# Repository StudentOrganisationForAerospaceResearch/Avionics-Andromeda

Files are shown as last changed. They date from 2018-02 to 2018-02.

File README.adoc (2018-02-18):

= Andromeda Sensor Development Board

Andromeda is the development board for SOAR's 2018 competition avionics system.

Hardware Designs are incremented by version.
For example; *AndromedaV1* is version 1.

The design files for each version are available along with pdf schematics,
assembly drawings and gerber files.

Each hardware version contains the following design files
----

* ___VX.pro - Kicad project
* ___VX.sch - Kicad main schematic
* ___VX.kicad_pcb - Kicad PCB design
* ___.sch - several hierarchical schematic
* ___V.net - Kicad netlist file
* ___VX-cache.dcm - Kicad component description cache
* ___VX-cache.lib - Kicad component library cache
* ___VX-Schematic.pdf - PDF Schematic
* ___VX-AssemblyDrawing.pdf PDF export of fabrication layer
* Gerbers - Gerber files exported with protel extensions
----

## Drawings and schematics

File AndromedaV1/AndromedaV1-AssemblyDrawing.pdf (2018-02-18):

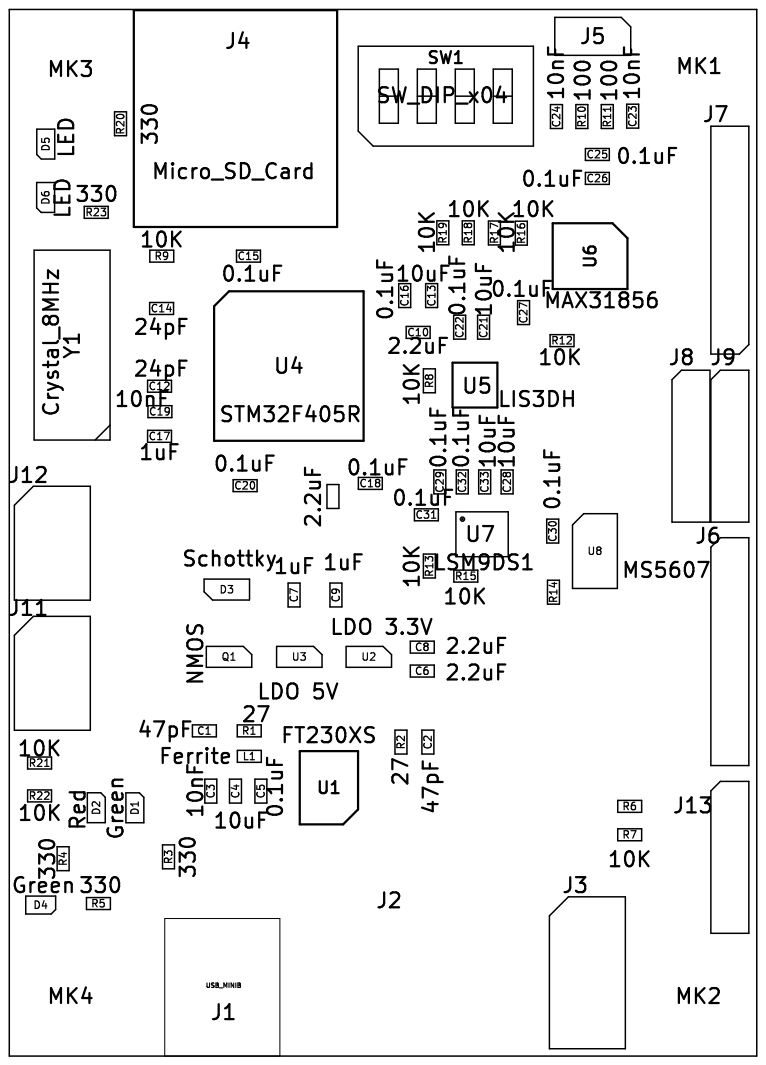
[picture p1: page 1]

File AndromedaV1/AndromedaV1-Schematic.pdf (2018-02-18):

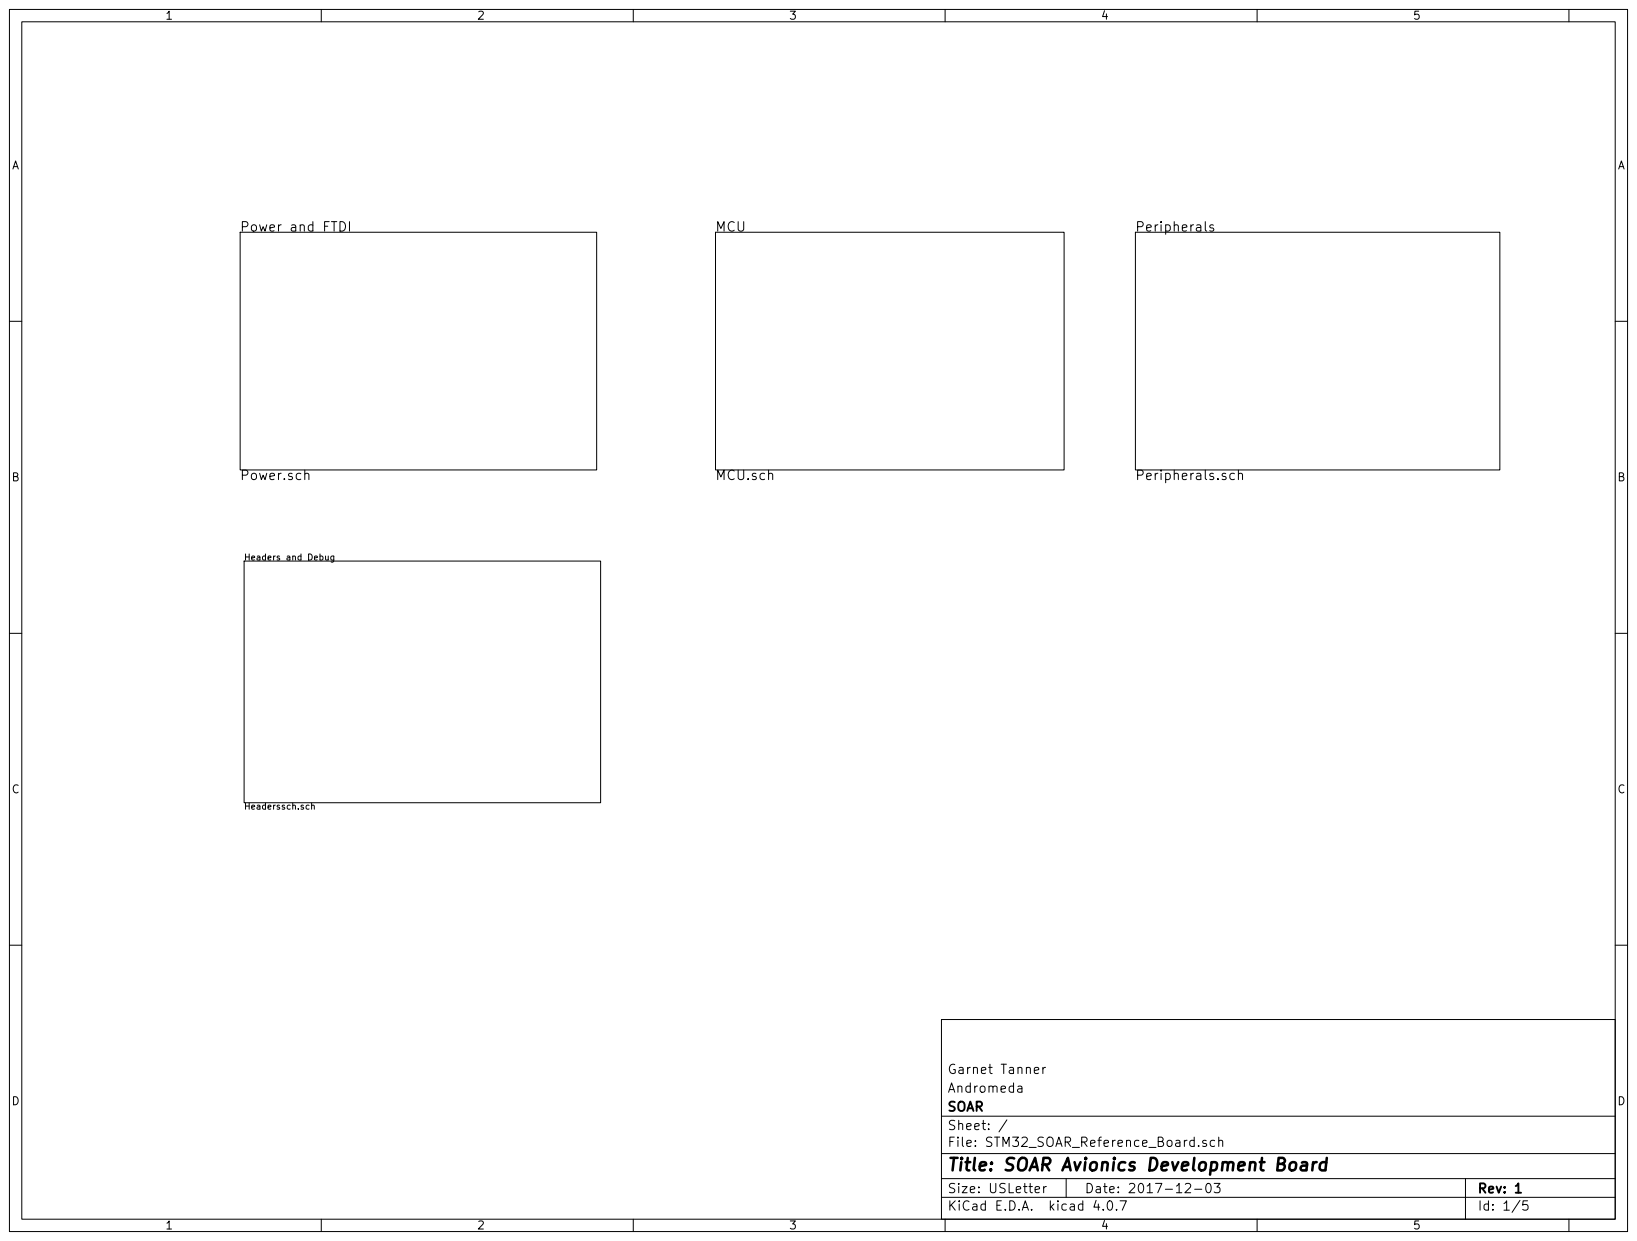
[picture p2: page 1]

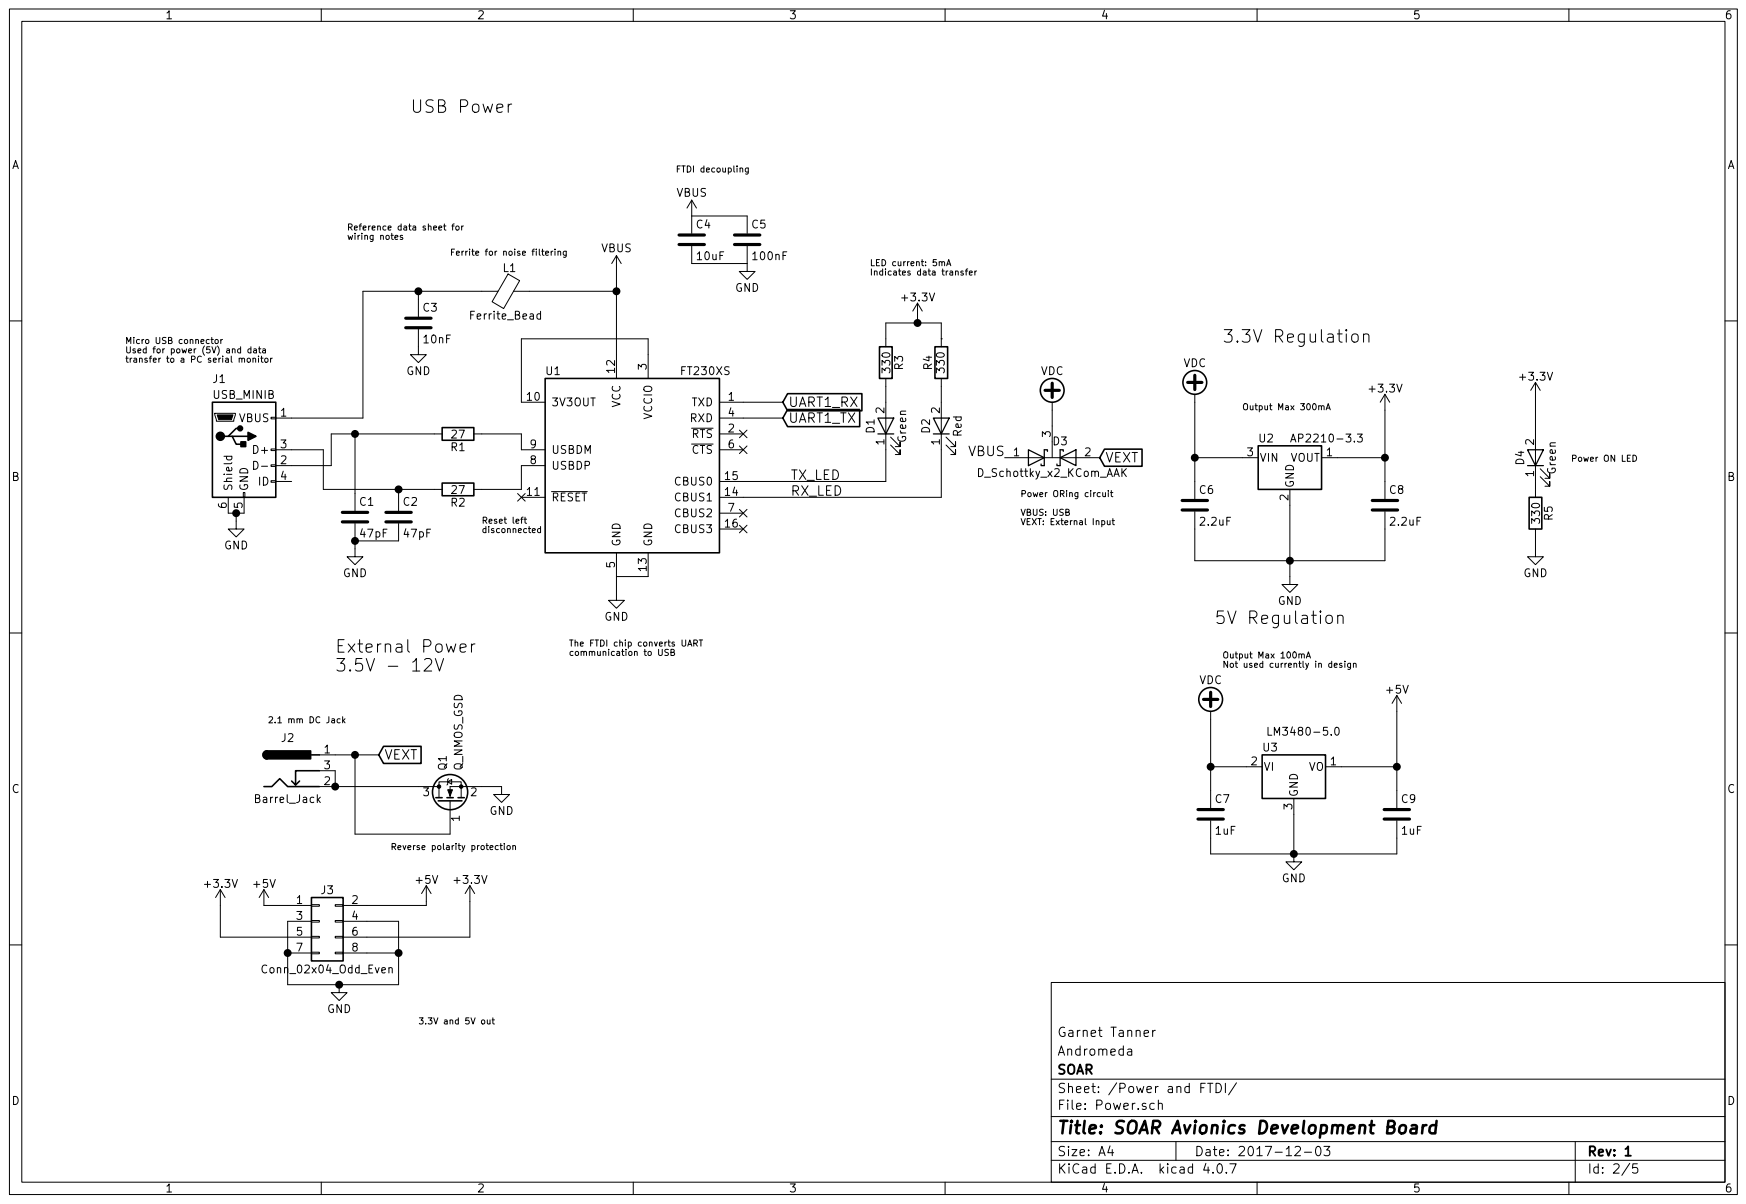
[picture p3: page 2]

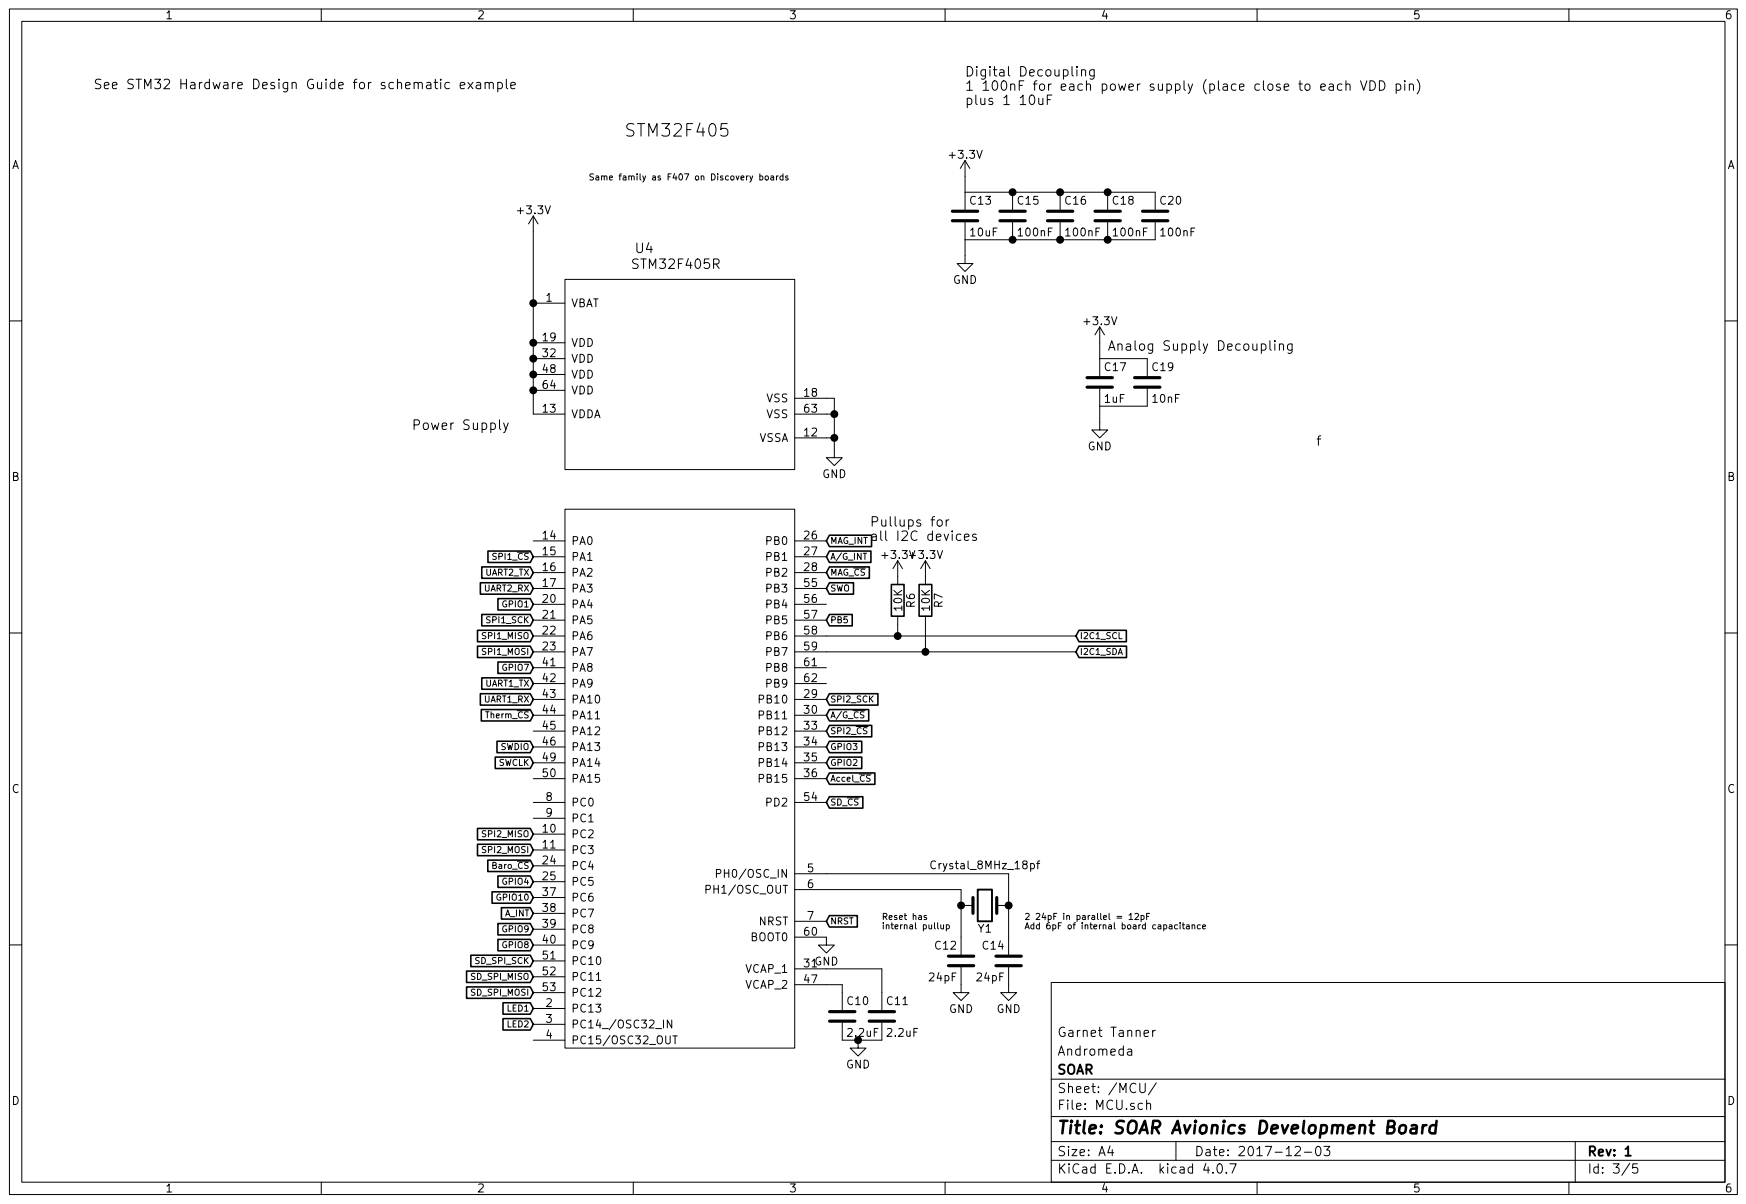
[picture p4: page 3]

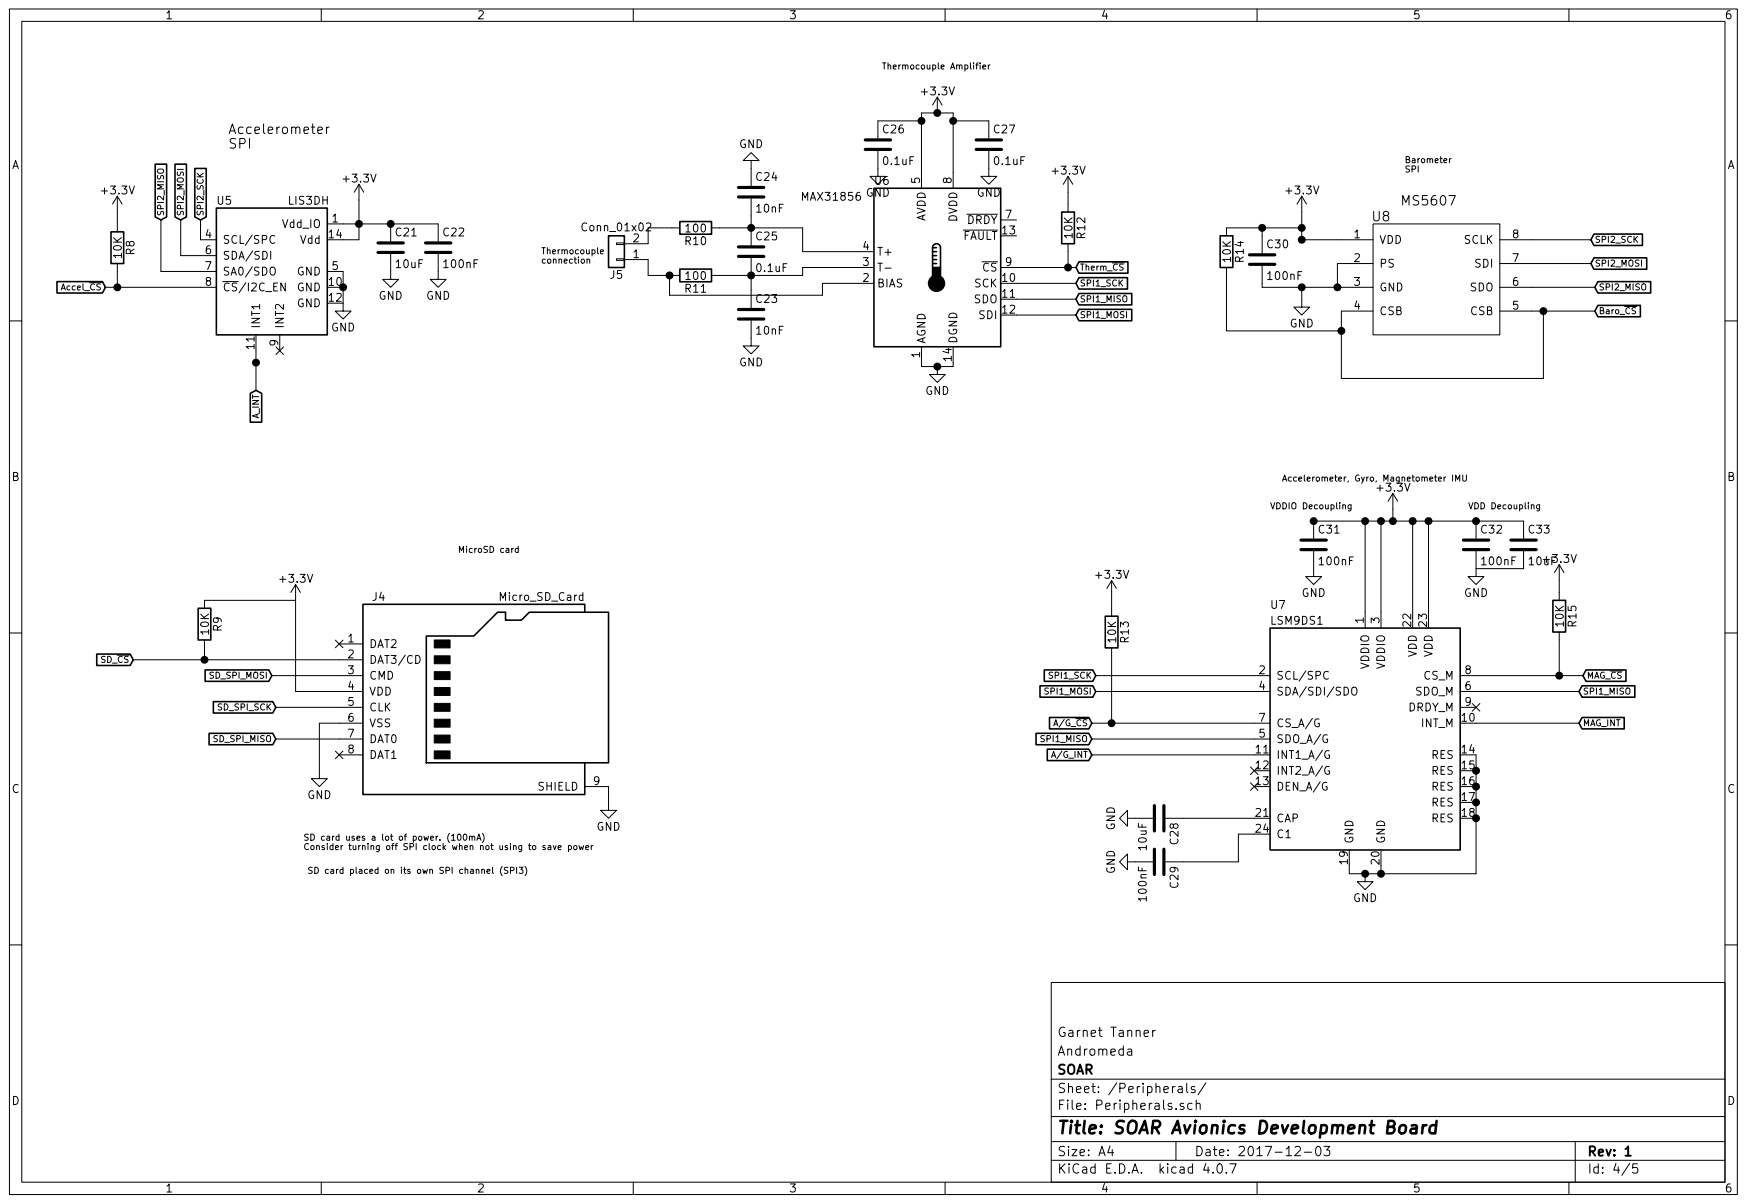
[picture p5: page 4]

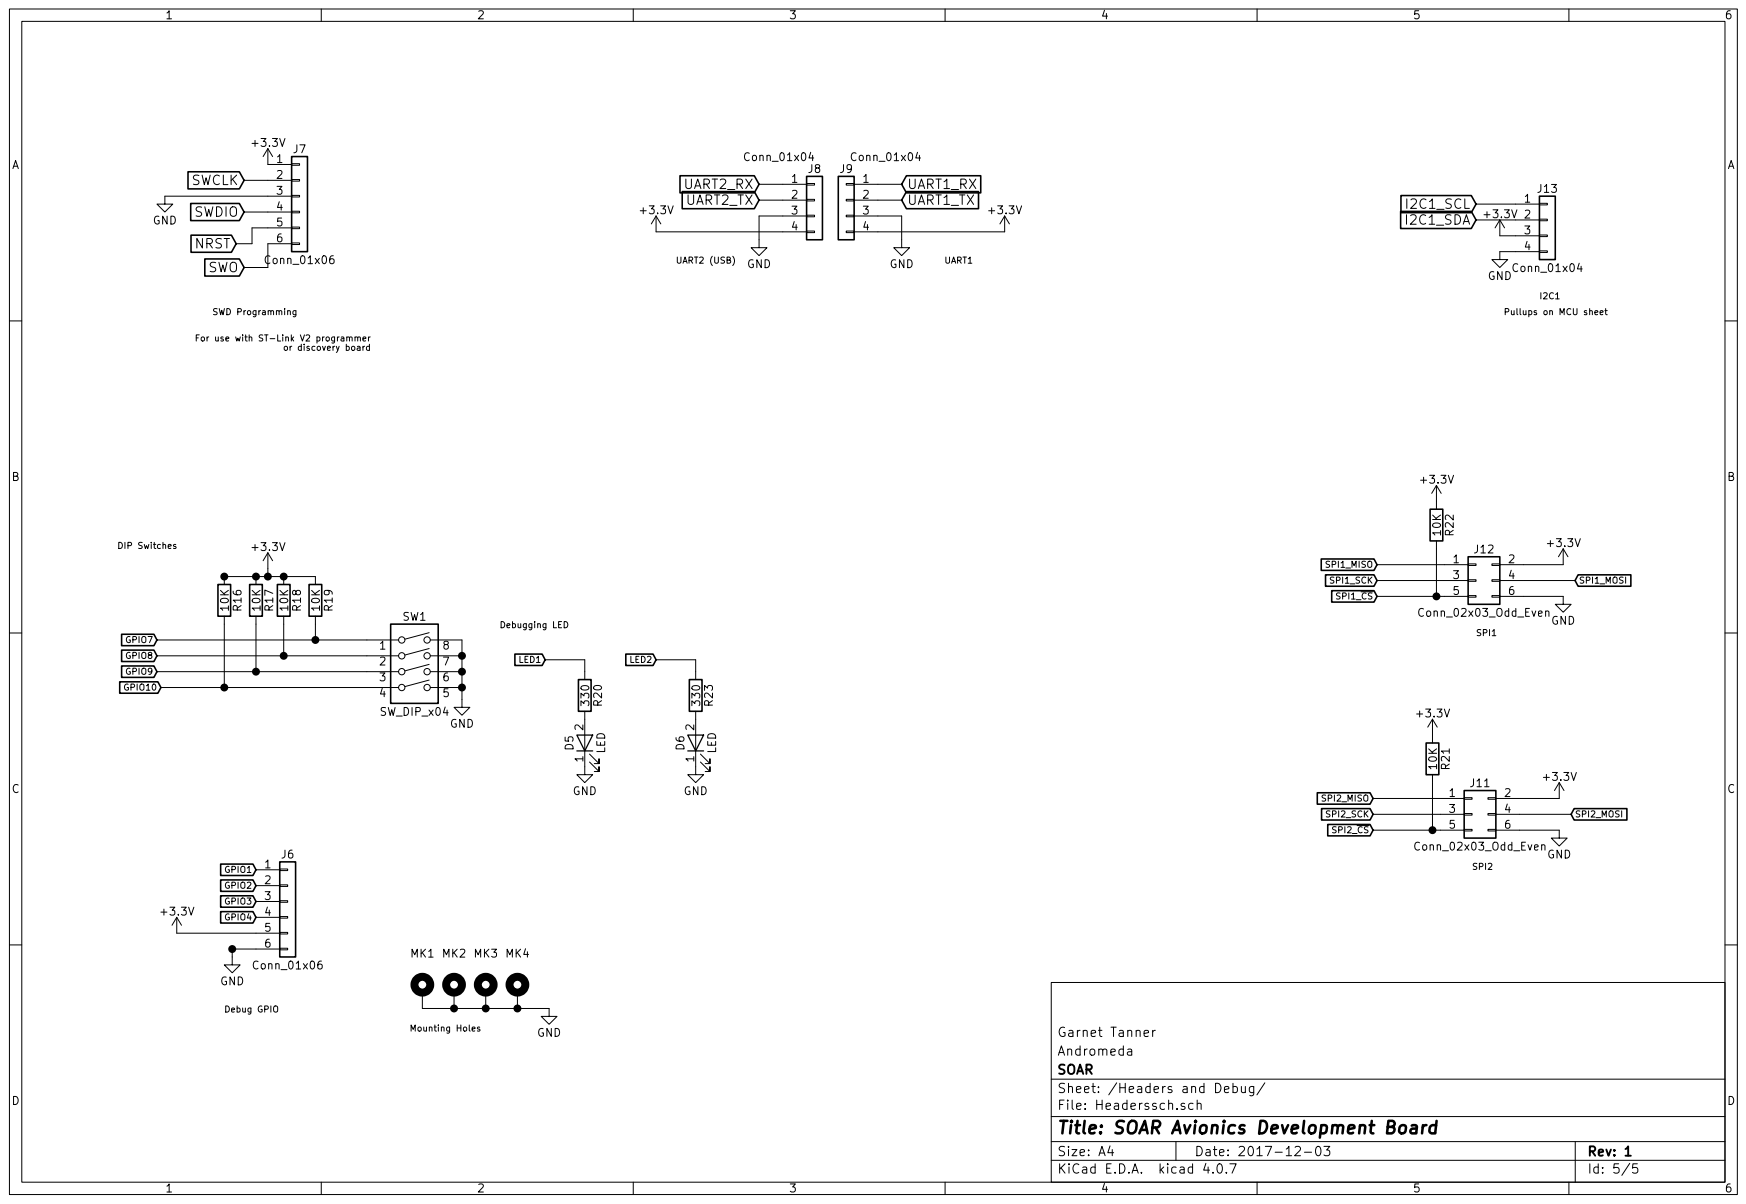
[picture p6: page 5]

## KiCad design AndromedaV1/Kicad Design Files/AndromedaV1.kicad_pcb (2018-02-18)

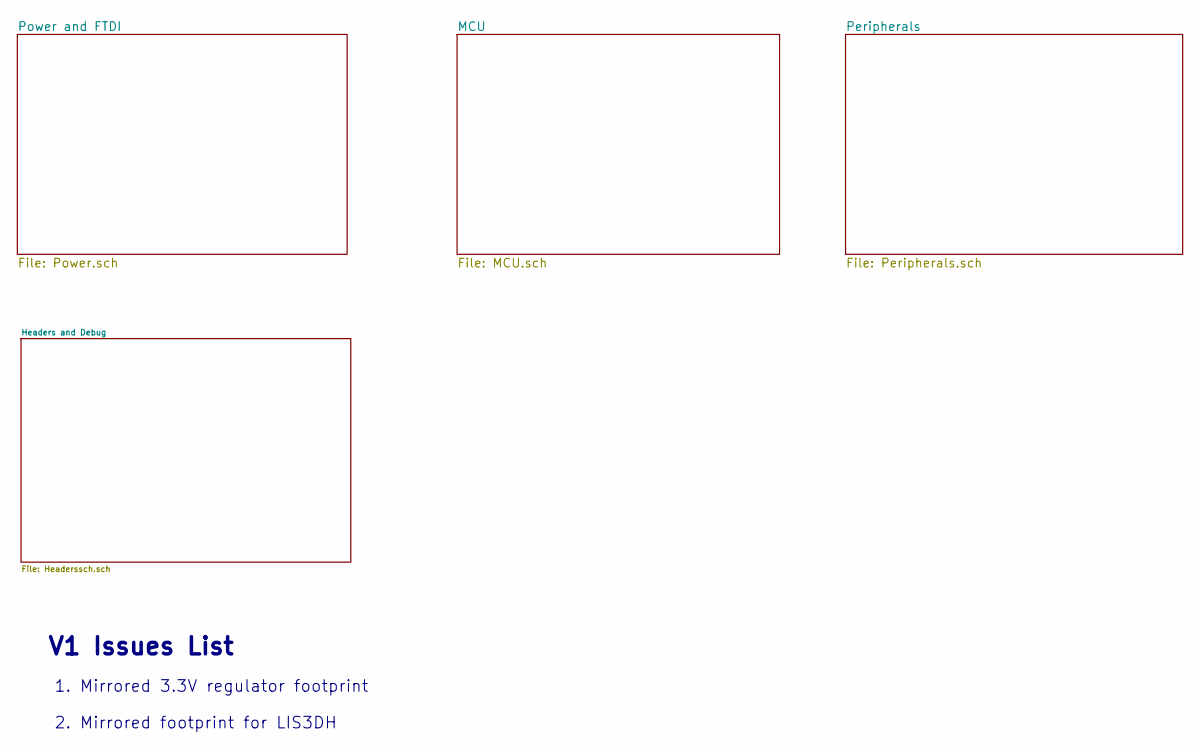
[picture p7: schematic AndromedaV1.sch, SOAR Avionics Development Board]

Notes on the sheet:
V1 Issues List
1. Mirrored 3.3V regulator footprint
2. Mirrored footprint for LIS3DH

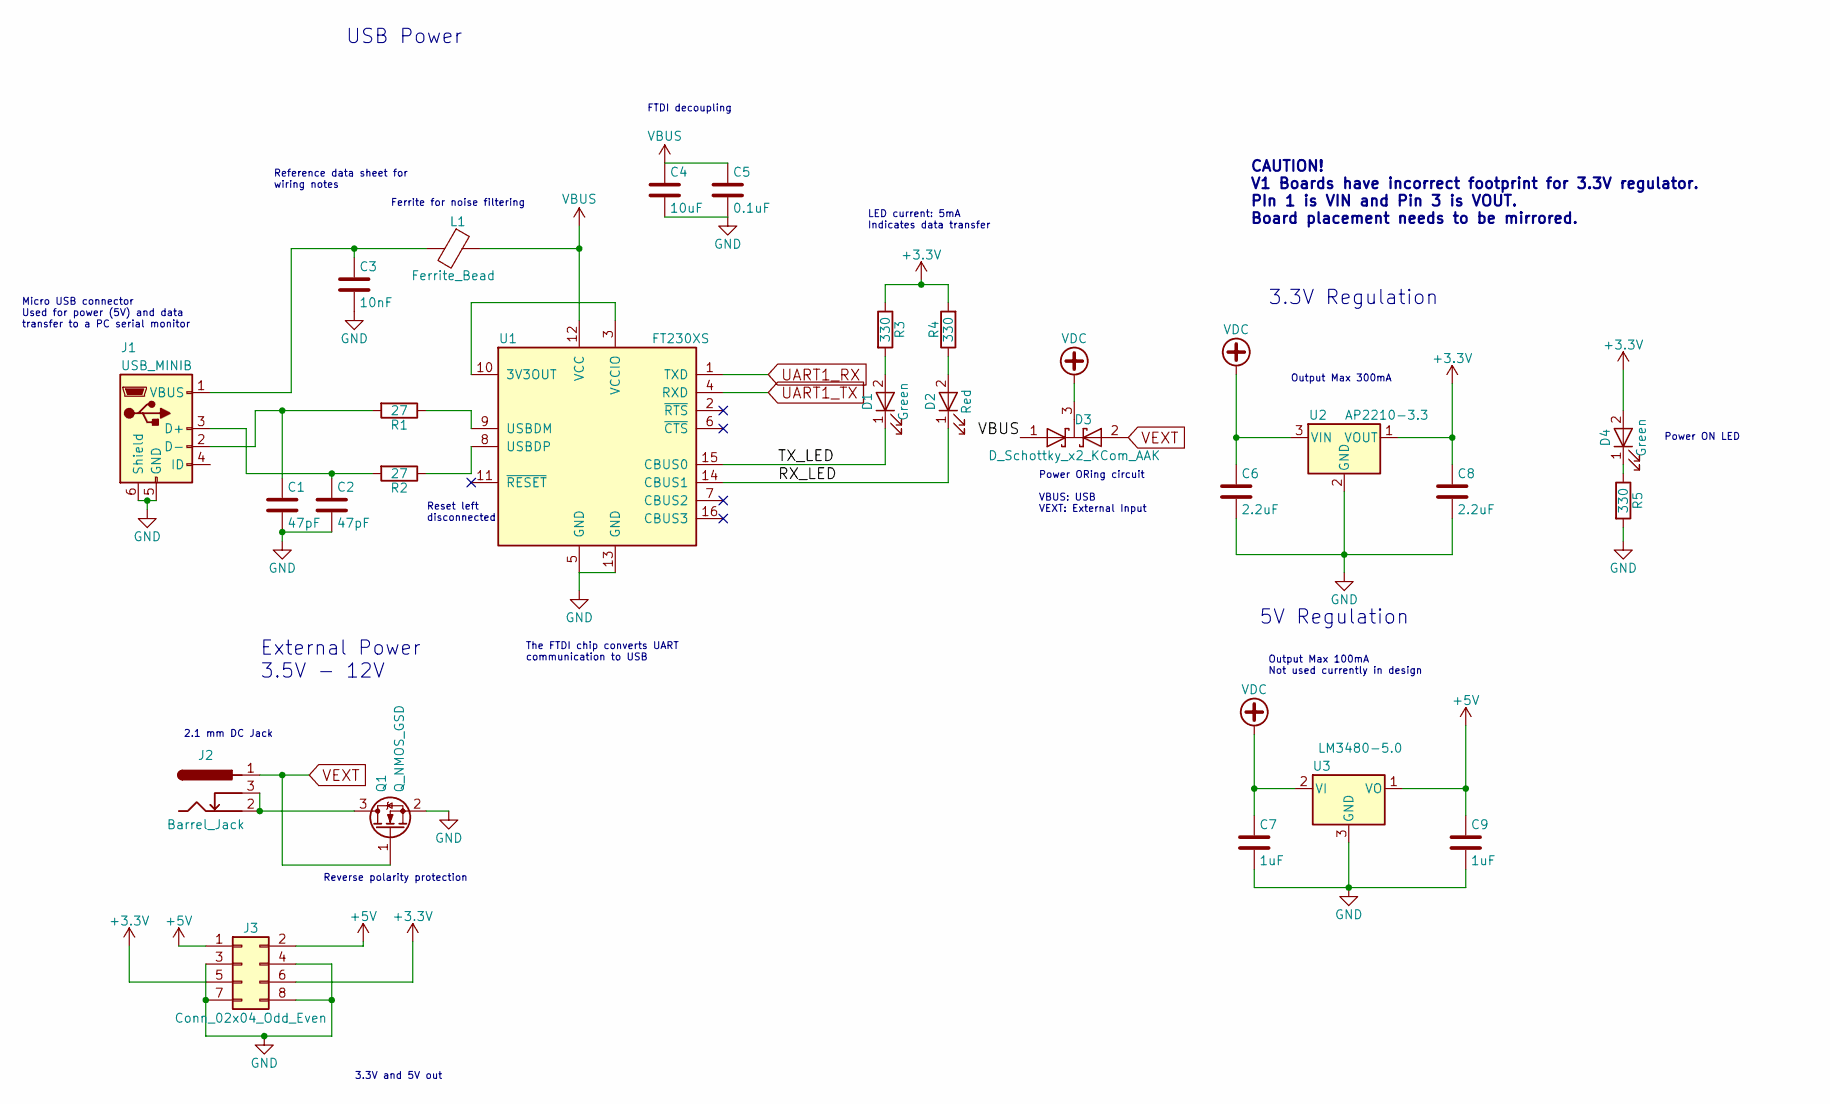
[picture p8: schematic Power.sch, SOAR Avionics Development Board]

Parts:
C1, C2: 47pF; C_0603_1608Metric
C3: 10nF; C_0603_1608Metric
C4: 10uF; C_0603_1608Metric
C5: 0.1uF; C_0603_1608Metric
C6, C8: 2.2uF; C_0603_1608Metric
C7, C9: 1uF; C_0603_1608Metric
D1, D4: Green; LED_0805_2012Metric; Digikey LG R971-KN-1
D2: Red; LED_0805_2012Metric; Digikey 475-1278-1-ND
D3: D_Schottky_x2_KCom_AAK; SOT-23; Digikey 1727-5188-1-ND
J1: USB_MINIB; USB-Mini-B; Digikey 690-005-299-043
J2: Barrel_Jack; CUI_PJ-102A; Digikey CP-102A-ND
J3: Conn_02x04_Odd_Even; PinHeader_2x04_P2.54mm_Vertical
L1: Ferrite_Bead; L_0603_1608Metric; Digikey 732-1593-1-ND
Q1: Q_NMOS_GSD; SOT-23; Digikey DMN3023L-7DICT-ND
R1, R2: 27; R_0603_1608Metric
R3, R4, R5: 330; R_0603_1608Metric
U1: FT230XS; SSOP-16_3.9x4.9mm_P0.635mm; Digikey 768-1135-1-ND
U2: AP2210-3.3; SOT-23; Digikey AP2210N-3.3TRG1
U3: LM3480-5.0; SOT-23; Digikey LM3480IM3X-5.0/NOPBCT-ND

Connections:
+3V3: C8.1, D4.2 (A), J3.5, J3.6, R3.1, R4.2, U2.1 (VOUT); also elsewhere on the board
+5V: C9.1, J3.1, J3.2, U3.1 (VO)
/Power and FTDI/RX_LED: D2.1 (K), U1.14 (CBUS1)
/Power and FTDI/TX_LED: D1.1 (K), U1.15 (CBUS0)
GND: C1.2, C2.2, C3.2, C4.2, C5.2, C6.2, C7.2, C8.2, C9.2, J1.5 (GND), J1.6 (Shield), J3.3, J3.4, J3.7, J3.8, Q1.2 (S), R5.2, U1.5 (GND), U1.13 (GND), U2.2 (GND), U3.3 (GND); also elsewhere on the board
unnamed: C1.1, J1.2 (D-), R1.2
unnamed: C2.1, J1.3 (D+), R2.2
unnamed: C3.1, J1.1 (VBUS), L1.2
unnamed: D1.2 (A), R3.2
unnamed: D2.2 (A), R4.1
unnamed: D4.1 (K), R5.1
unnamed: J2.2, J2.3, Q1.3 (D)
unnamed: R1.1, U1.9 (USBDM)
unnamed: R2.1, U1.8 (USBDP)
unnamed: U1.3 (VCCIO), U1.10 (3V3OUT)
UART1_RX: U1.1 (TXD); also elsewhere on the board
UART1_TX: U1.4 (RXD); also elsewhere on the board
VBUS: C4.1, C5.1, D3.1 (A), L1.1, U1.12 (VCC)
VDC: C6.1, C7.1, D3.3 (K), U2.3 (VIN), U3.2 (VI)
VEXT: D3.2 (A), J2.1, Q1.1 (G)

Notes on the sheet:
Reset left disconnected
Output Max 300mA
Power ON LED
LED current: 5mA Indicates data transfer
The FTDI chip converts UART communication to USB
Power ORing circuit VBUS: USB VEXT: External Input
Micro USB connector Used for power (5V) and data transfer to a PC serial monitor
Reference data sheet for wiring notes
Ferrite for noise filtering
FTDI decoupling
Reverse polarity protection
2.1 mm DC Jack
3.3V and 5V out
External Power 3.5V - 12V
USB Power
3.3V Regulation
Output Max 100mA Not used currently in design
5V Regulation
CAUTION! V1 Boards have incorrect footprint for 3.3V regulator. PIn 1 is VIN and Pin 3 is VOUT. Board placement needs to be mirrored.

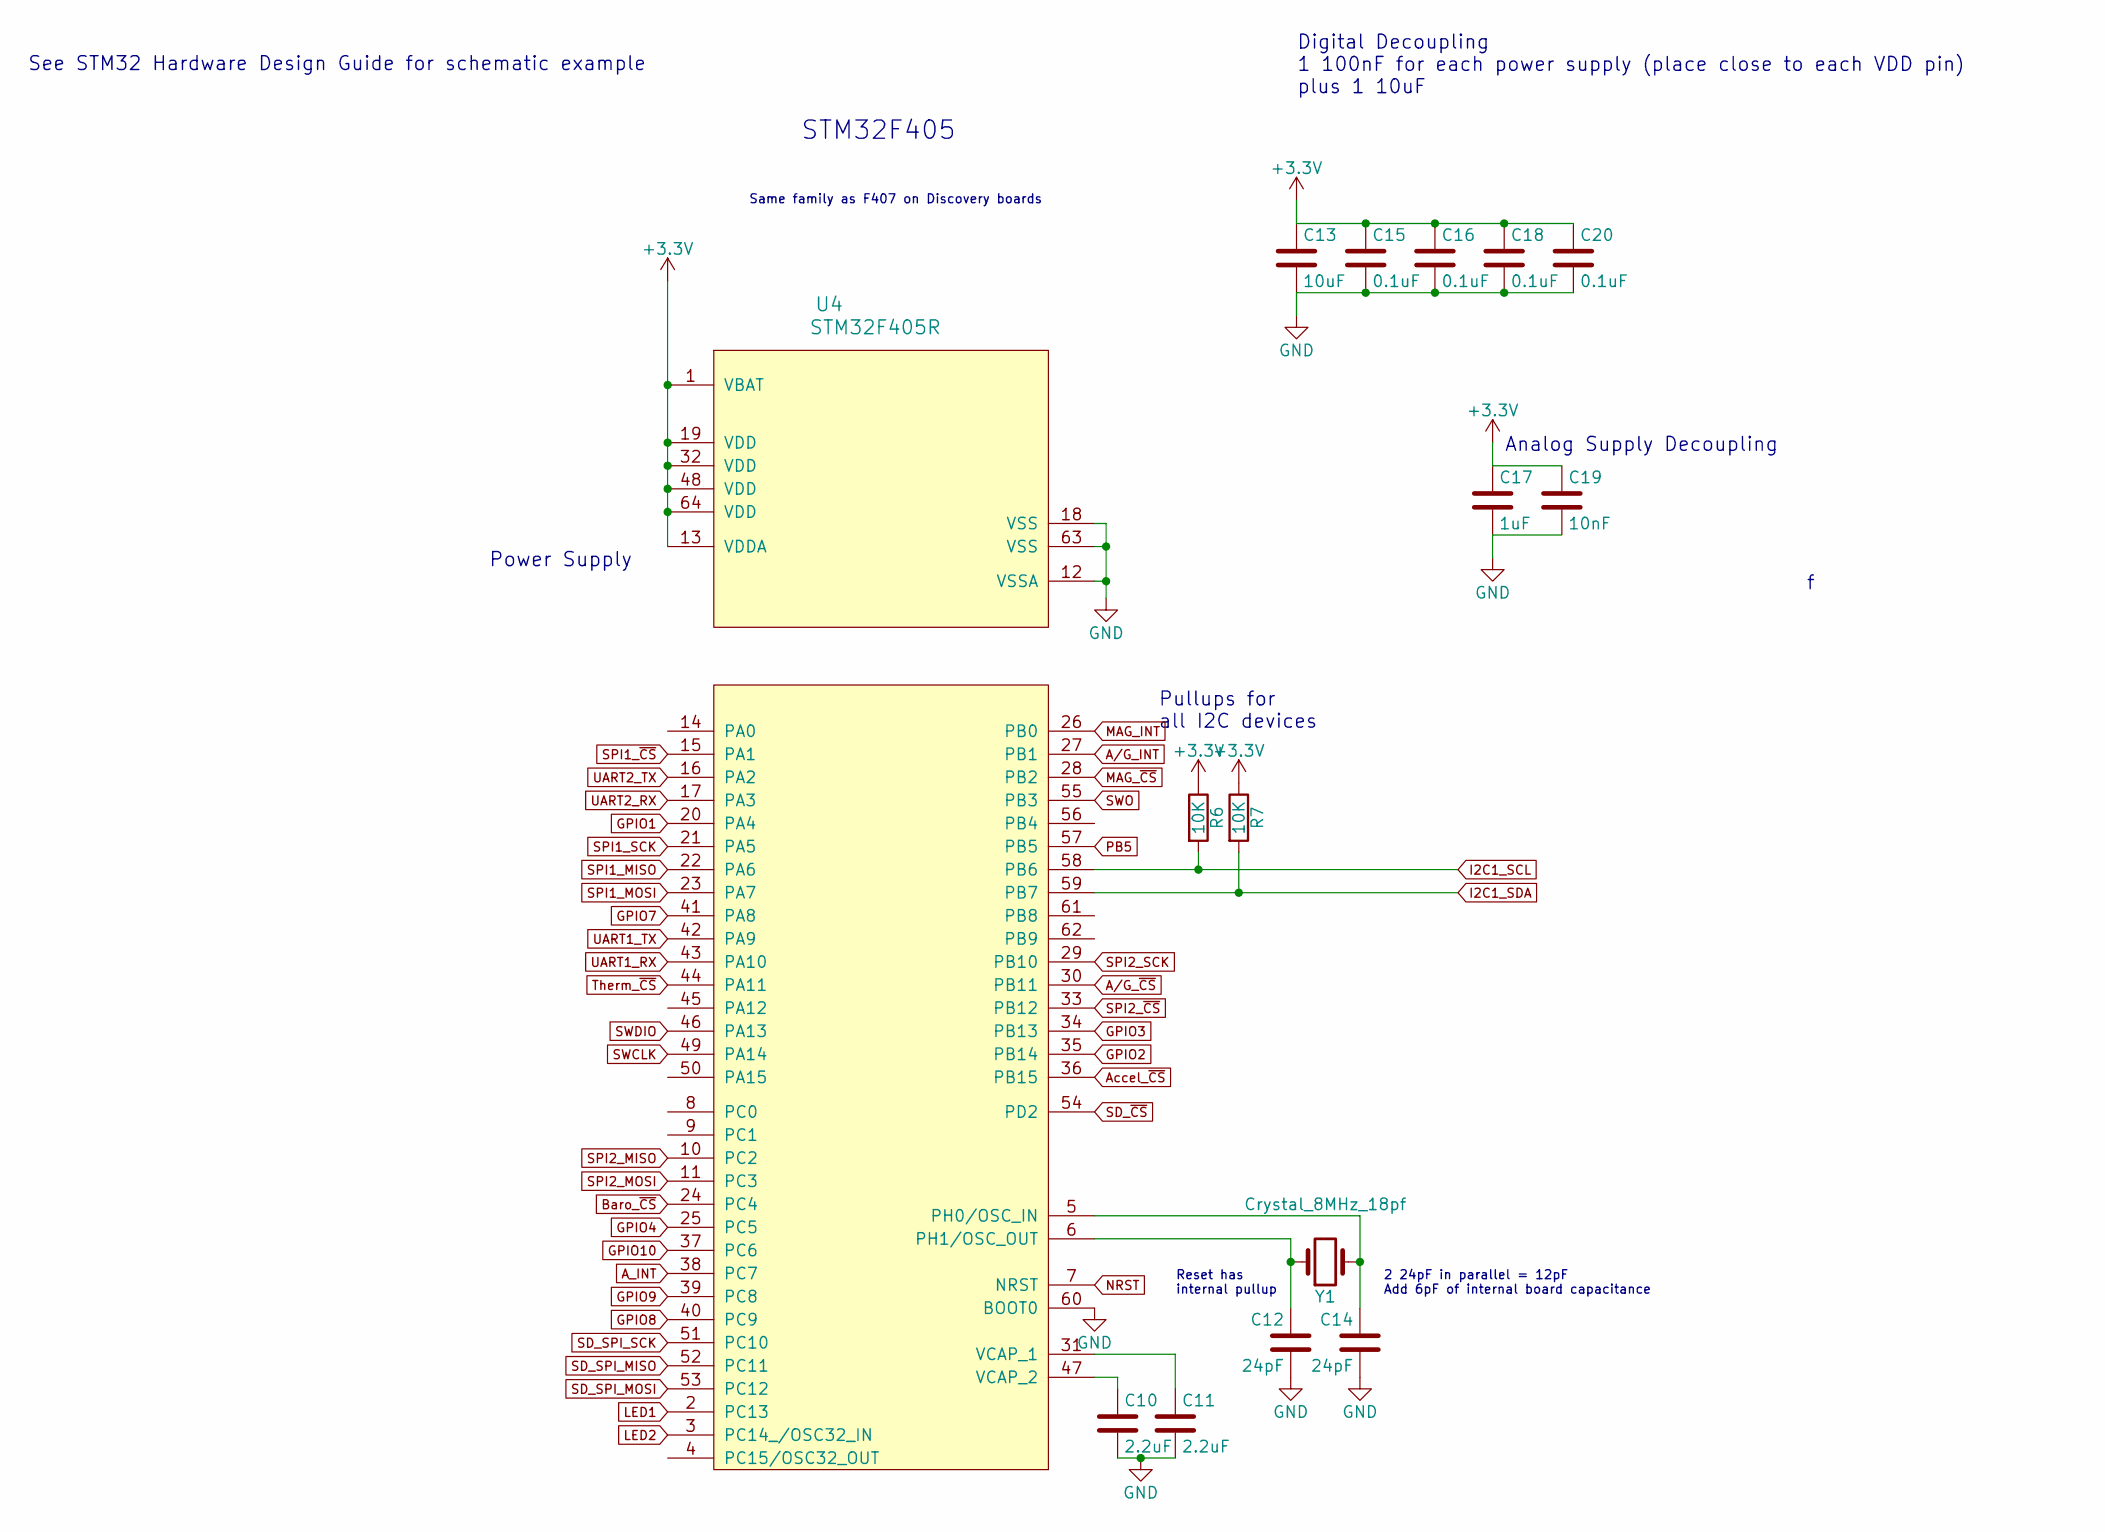
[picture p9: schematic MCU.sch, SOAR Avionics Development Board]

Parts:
C10, C11: 2.2uF; C_0603_1608Metric
C12, C14: 24pF; C_0603_1608Metric
C13: 10uF; C_0603_1608Metric
C15, C16, C18, C20: 0.1uF; C_0603_1608Metric
C17: 1uF; C_0603_1608Metric
C19: 10nF; C_0603_1608Metric
R6, R7: 10K; R_0603_1608Metric
U4: STM32F405R; LQFP-64_10x10mm_P0.5mm; Digikey 497-11767-ND
Y1: Crystal_8MHz_18pf; Crystal_SMD_SeikoEpson_MA505-2Pin_12.7x5.1mm; Digikey 535-9089-1-ND

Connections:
+3V3: C13.1, C15.1, C16.1, C17.1, C18.1, C19.1, C20.1, R6.1, R7.1, U4.1 (VBAT), U4.13 (VDDA), U4.19 (VDD), U4.32 (VDD), U4.48 (VDD), U4.64 (VDD); also elsewhere on the board
A/G_INT: U4.27 (PB1); also elsewhere on the board
A/G_~CS: U4.30 (PB11); also elsewhere on the board
A_INT: U4.38 (PC7); also elsewhere on the board
Accel_~CS: U4.36 (PB15); also elsewhere on the board
Baro_~CS: U4.24 (PC4); also elsewhere on the board
GND: C10.2, C11.2, C12.2, C13.2, C14.2, C15.2, C16.2, C17.2, C18.2, C19.2, C20.2, U4.12 (VSSA), U4.18 (VSS), U4.60 (BOOT0), U4.63 (VSS); also elsewhere on the board
GPIO1: U4.20 (PA4); also elsewhere on the board
GPIO2: U4.35 (PB14); also elsewhere on the board
GPIO3: U4.34 (PB13); also elsewhere on the board
GPIO4: U4.25 (PC5); also elsewhere on the board
GPIO7: U4.41 (PA8); also elsewhere on the board
GPIO8: U4.40 (PC9); also elsewhere on the board
GPIO9: U4.39 (PC8); also elsewhere on the board
GPIO10: U4.37 (PC6); also elsewhere on the board
I2C1_SCL: R6.2, U4.58 (PB6); also elsewhere on the board
I2C1_SDA: R7.2, U4.59 (PB7); also elsewhere on the board
LED1: U4.2 (PC13); also elsewhere on the board
LED2: U4.3 (PC14_/OSC32_IN); also elsewhere on the board
MAG_INT: U4.26 (PB0); also elsewhere on the board
MAG_~CS: U4.28 (PB2); also elsewhere on the board
NRST: U4.7 (NRST); also elsewhere on the board
unnamed: C10.1, U4.47 (VCAP_2)
unnamed: C11.1, U4.31 (VCAP_1)
unnamed: C12.1, U4.6 (PH1/OSC_OUT), Y1.1
unnamed: C14.1, U4.5 (PH0/OSC_IN), Y1.2
PB5: U4.57 (PB5)
SD_SPI_MISO: U4.52 (PC11); also elsewhere on the board
SD_SPI_MOSI: U4.53 (PC12); also elsewhere on the board
SD_SPI_SCK: U4.51 (PC10); also elsewhere on the board
SD_~CS: U4.54 (PD2); also elsewhere on the board
SPI1_MISO: U4.22 (PA6); also elsewhere on the board
SPI1_MOSI: U4.23 (PA7); also elsewhere on the board
SPI1_SCK: U4.21 (PA5); also elsewhere on the board
SPI1_~CS: U4.15 (PA1); also elsewhere on the board
SPI2_MISO: U4.10 (PC2); also elsewhere on the board
SPI2_MOSI: U4.11 (PC3); also elsewhere on the board
SPI2_SCK: U4.29 (PB10); also elsewhere on the board
SPI2_~CS: U4.33 (PB12); also elsewhere on the board
SWCLK: U4.49 (PA14); also elsewhere on the board
SWDIO: U4.46 (PA13); also elsewhere on the board
SWO: U4.55 (PB3); also elsewhere on the board
Therm_~CS: U4.44 (PA11); also elsewhere on the board
UART1_RX: U4.43 (PA10); also elsewhere on the board
UART1_TX: U4.42 (PA9); also elsewhere on the board
UART2_RX: U4.17 (PA3); also elsewhere on the board
UART2_TX: U4.16 (PA2); also elsewhere on the board

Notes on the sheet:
Reset has internal pullup
Digital Decoupling 1 100nF for each power supply (place close to each VDD pin) plus 1 10uF
Analog Supply Decoupling
Pullups for all I2C devices
See STM32 Hardware Design Guide for schematic example
Power Supply
2 24pF in parallel = 12pF Add 6pF of internal board capacitance
STM32F405
Same family as F407 on Discovery boards

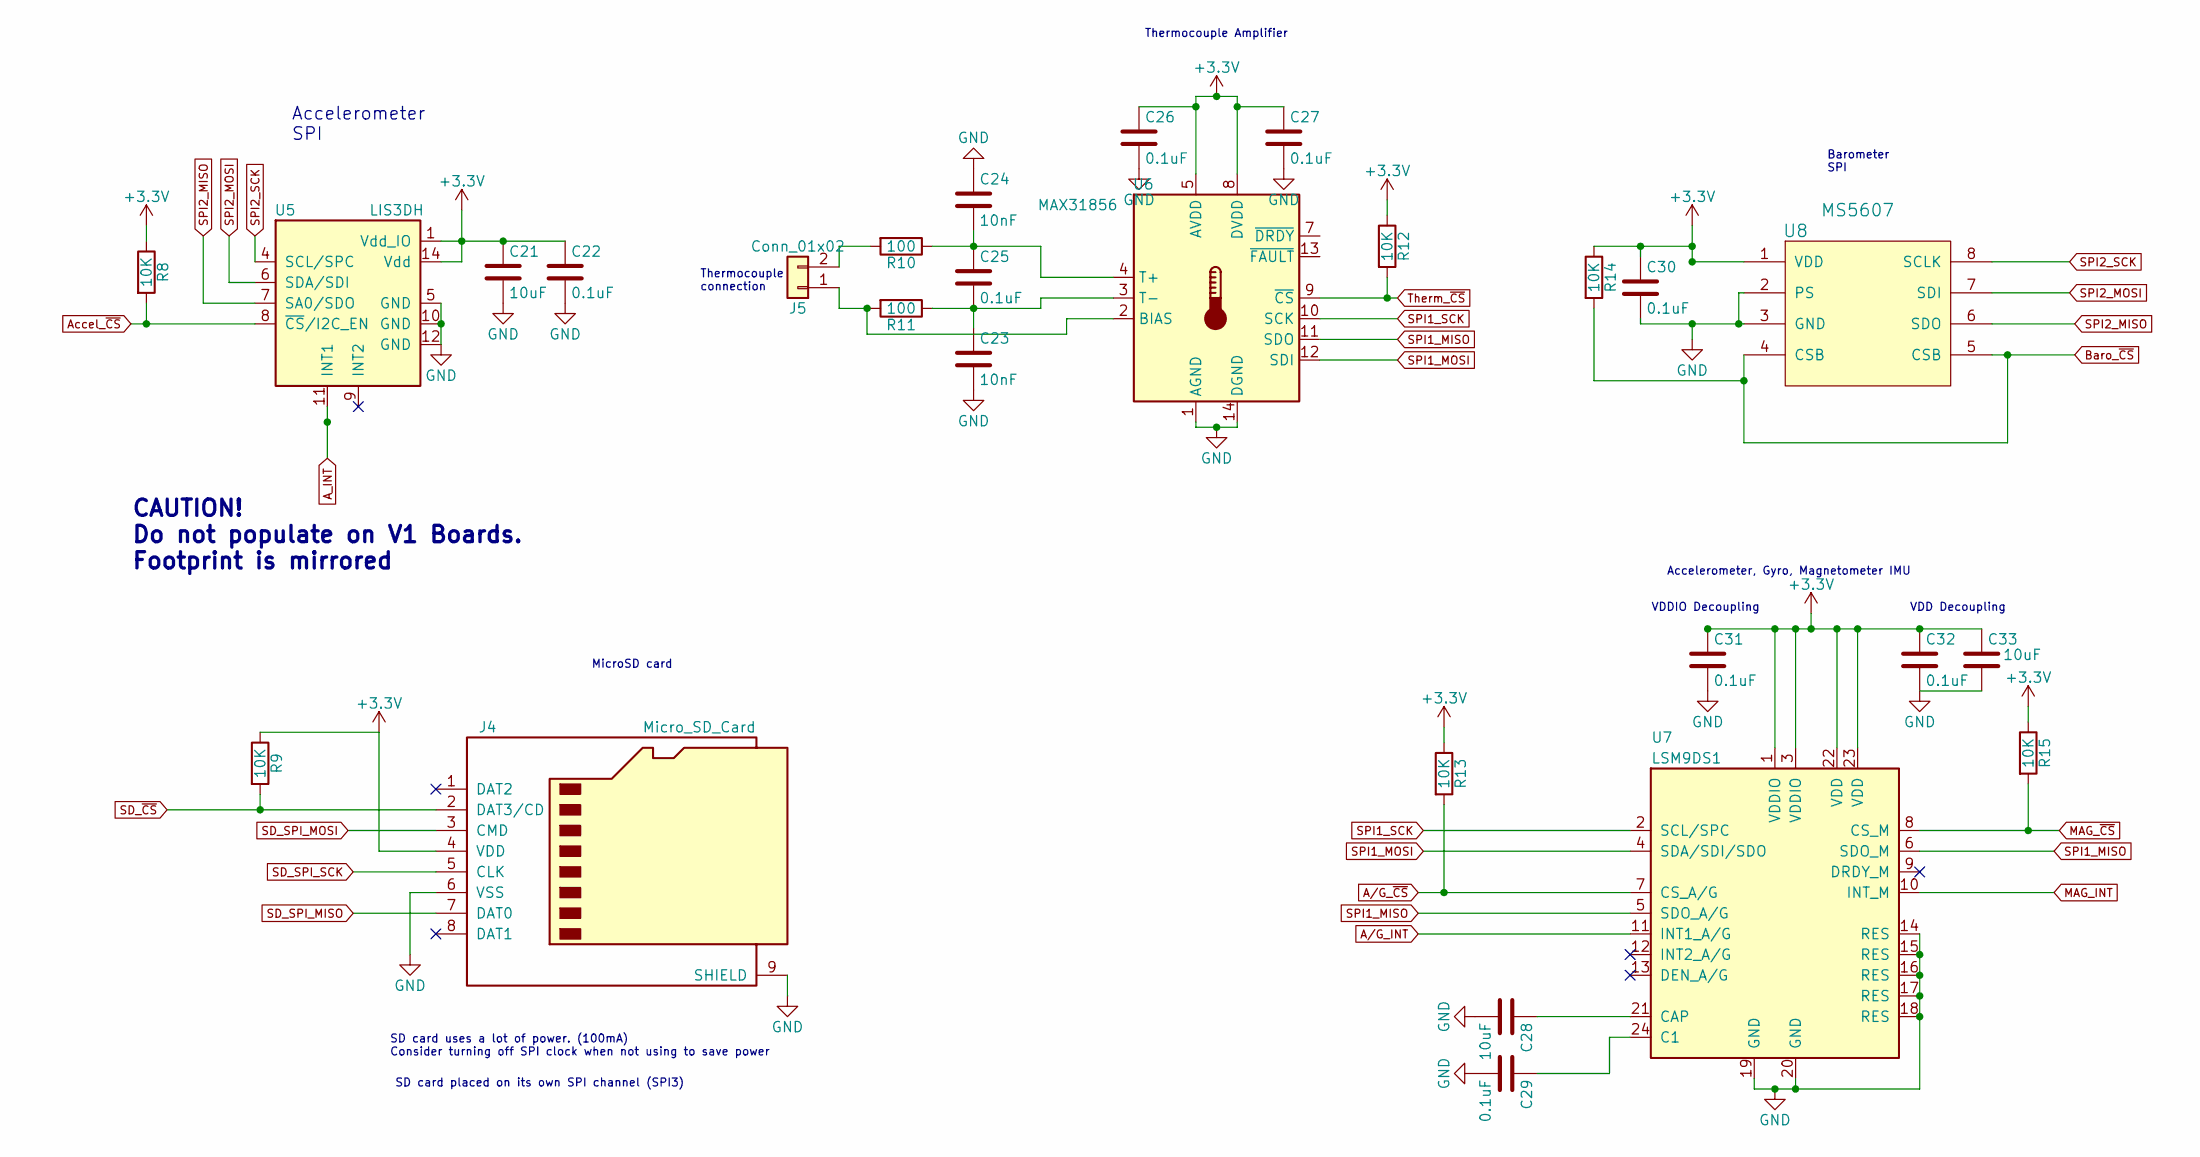
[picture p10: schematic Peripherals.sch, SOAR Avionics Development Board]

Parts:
C21, C28, C33: 10uF; C_0603_1608Metric
C22, C25, C26, C27, C29, C30, C31, C32: 0.1uF; C_0603_1608Metric
C23, C24: 10nF; C_0603_1608Metric
J4: Micro_SD_Card; Conn,Molex,Hinged_microSD; Digikey 0472192001
J5: Conn_01x02; PinHeader_1x02_P2.54mm_Vertical
R8, R9, R12, R13, R14, R15: 10K; R_0603_1608Metric
R10, R11: 100; R_0603_1608Metric
U5: LIS3DH; LGA-16
U6: MAX31856; TSSOP-14_4.4x5mm_P0.65mm; Digikey MAX31856MUD+-ND
U7: LSM9DS1; LGA-24L_3x3.5mm_P0.43mm; Digikey 497-14946-1-ND
U8: MS5607; LGA-8_3x5mm_P1.25mm; Digikey MS560702BA03-00

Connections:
+3V3: C21.1, C22.1, C26.1, C27.1, C30.1, C31.1, C32.1, C33.1, J4.4 (VDD), R8.1, R9.1, R12.1, R13.1, R14.1, R15.1, U5.1 (Vdd_IO), U5.14 (Vdd), U6.5 (AVDD), U6.8 (DVDD), U7.1 (VDDIO), U7.3 (VDDIO), U7.22 (VDD), U7.23 (VDD), U8.1 (VDD); also elsewhere on the board
A/G_INT: U7.11 (INT1_A/G); also elsewhere on the board
A/G_~CS: R13.2, U7.7 (CS_A/G); also elsewhere on the board
A_INT: U5.11 (INT1); also elsewhere on the board
Accel_~CS: R8.2, U5.8 (~CS~/I2C_EN); also elsewhere on the board
Baro_~CS: R14.2, U8.4 (CSB), U8.5 (CSB); also elsewhere on the board
GND: C21.2, C22.2, C23.2, C24.1, C26.2, C27.2, C28.2, C29.2, C30.2, C31.2, C32.2, C33.2, J4.6 (VSS), J4.9 (SHIELD), U5.5 (GND), U5.10 (GND), U5.12 (GND), U6.1 (AGND), U6.14 (DGND), U7.14 (RES), U7.15 (RES), U7.16 (RES), U7.17 (RES), U7.18 (RES), U7.19 (GND), U7.20 (GND), U8.2 (PS), U8.3 (GND); also elsewhere on the board
MAG_INT: U7.10 (INT_M); also elsewhere on the board
MAG_~CS: R15.2, U7.8 (CS_M); also elsewhere on the board
unnamed: C23.1, C25.2, R11.1, U6.3 (T-)
unnamed: C24.2, C25.1, R10.1, U6.4 (T+)
unnamed: C28.1, U7.21 (CAP)
unnamed: C29.1, U7.24 (C1)
unnamed: J5.1, R11.2, U6.2 (BIAS)
unnamed: J5.2, R10.2
SD_SPI_MISO: J4.7 (DAT0); also elsewhere on the board
SD_SPI_MOSI: J4.3 (CMD); also elsewhere on the board
SD_SPI_SCK: J4.5 (CLK); also elsewhere on the board
SD_~CS: J4.2 (DAT3/CD), R9.2; also elsewhere on the board
SPI1_MISO: U6.11 (SDO), U7.5 (SDO_A/G), U7.6 (SDO_M); also elsewhere on the board
SPI1_MOSI: U6.12 (SDI), U7.4 (SDA/SDI/SDO); also elsewhere on the board
SPI1_SCK: U6.10 (SCK), U7.2 (SCL/SPC); also elsewhere on the board
SPI2_MISO: U5.7 (SA0/SDO), U8.6 (SDO); also elsewhere on the board
SPI2_MOSI: U5.6 (SDA/SDI), U8.7 (SDI); also elsewhere on the board
SPI2_SCK: U5.4 (SCL/SPC), U8.8 (SCLK); also elsewhere on the board
Therm_~CS: R12.2, U6.9 (~CS); also elsewhere on the board

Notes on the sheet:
SD card uses a lot of power. (100mA) Consider turning off SPI clock when not using to save power
Accelerometer SPI
Barometer SPI
VDD Decoupling
VDDIO Decoupling
Thermocouple Amplifier
Thermocouple connection
MicroSD card
Accelerometer, Gyro, Magnetometer IMU
SD card placed on its own SPI channel (SPI3)
CAUTION! Do not populate on V1 Boards. Footprint is mirrored

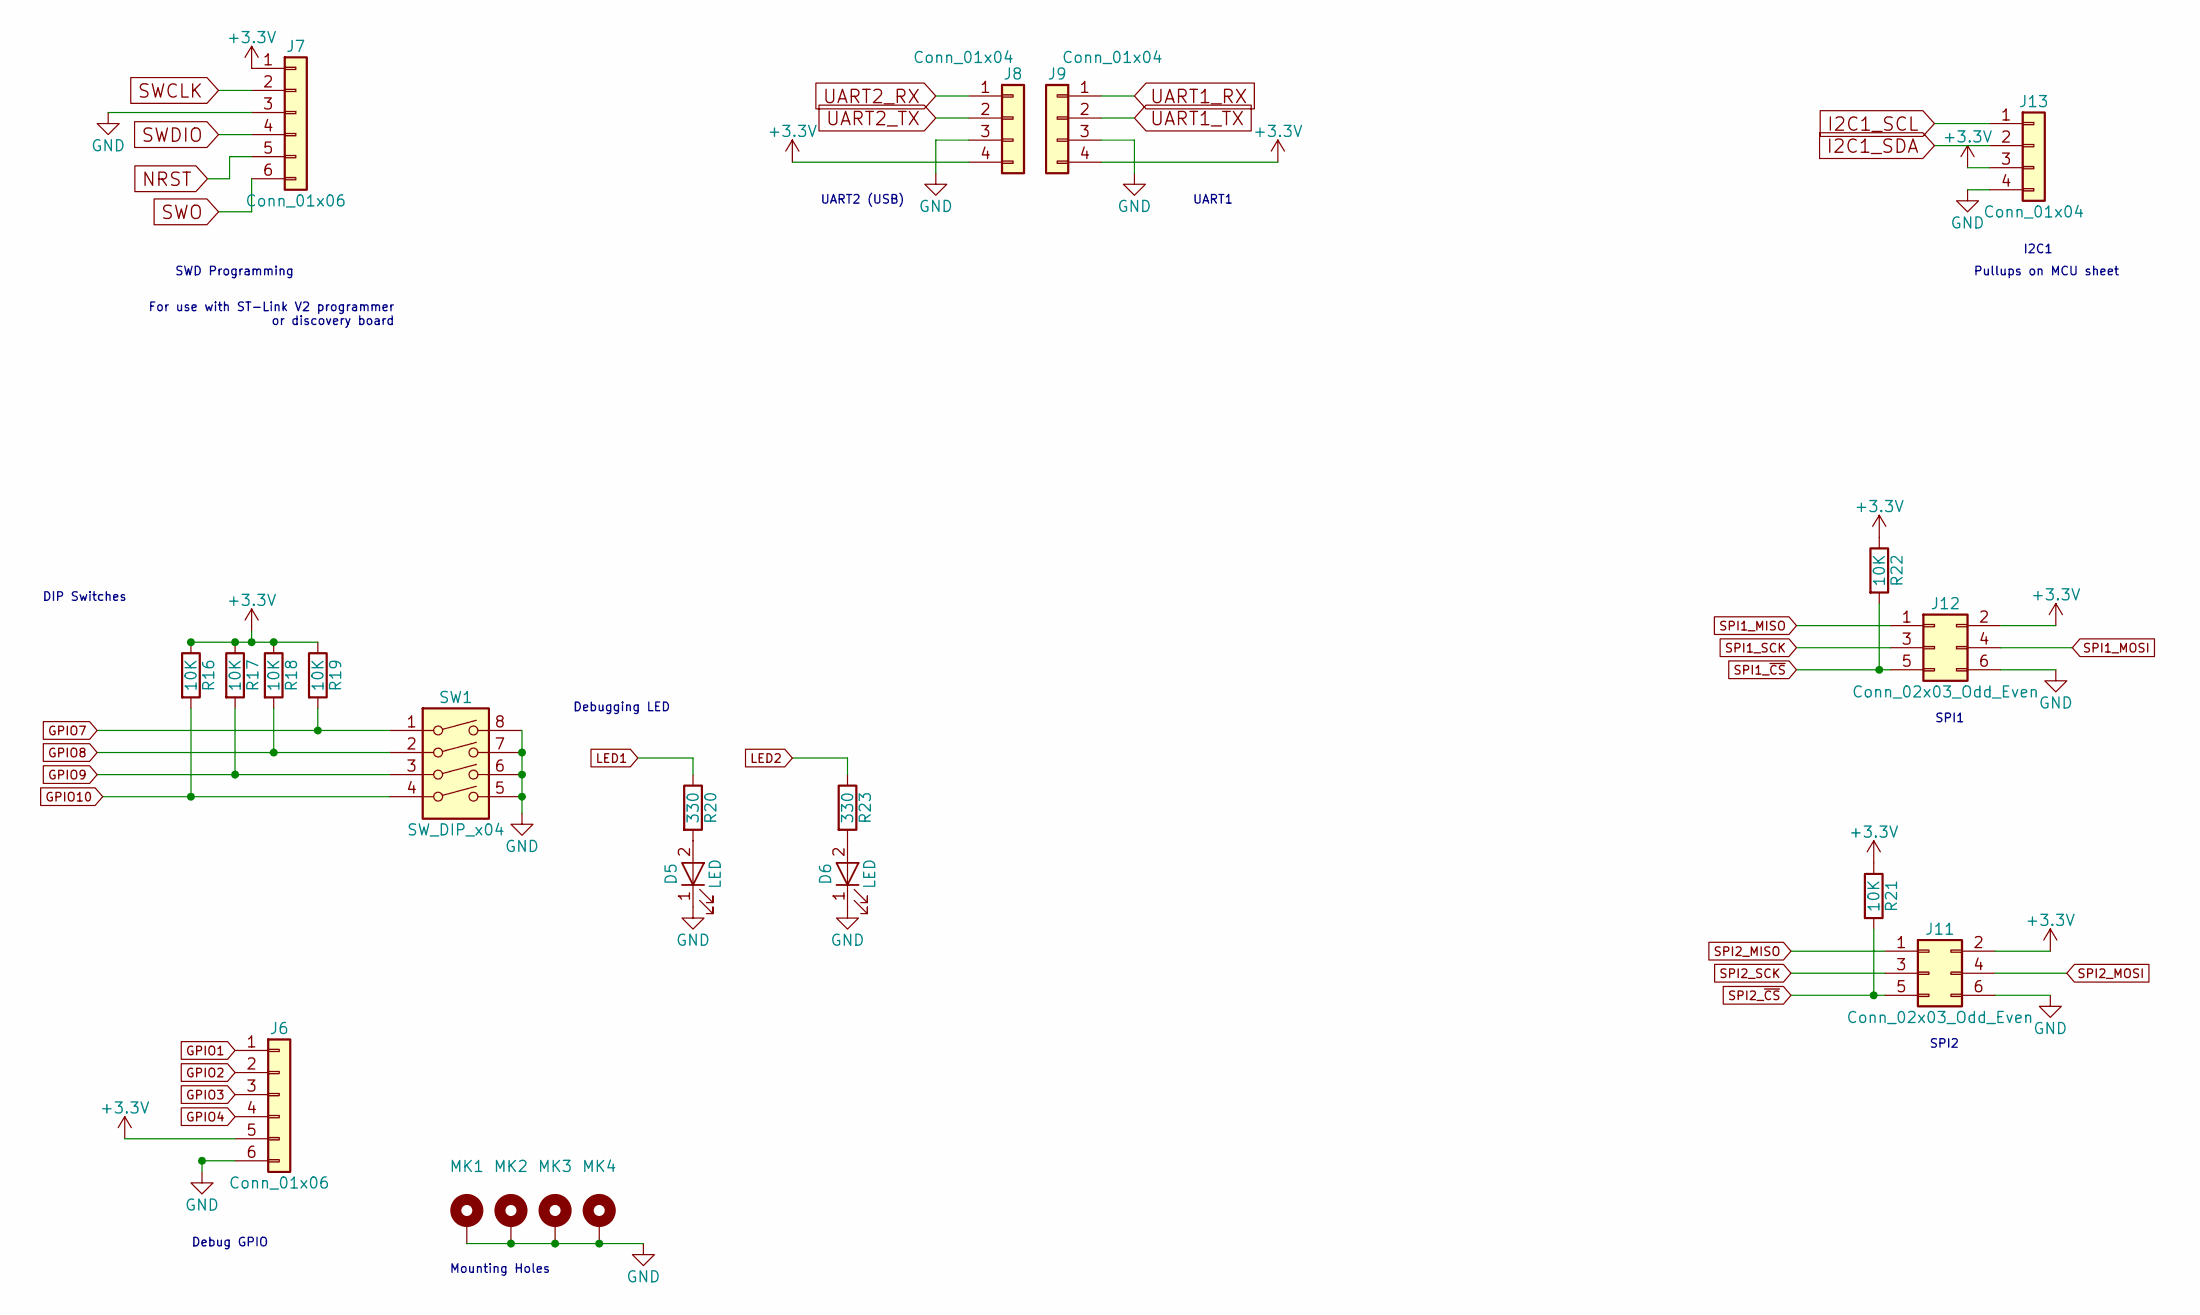
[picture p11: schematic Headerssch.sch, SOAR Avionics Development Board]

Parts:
D5, D6: LED; LED_0805_2012Metric
J6, J7: Conn_01x06; PinHeader_1x06_P2.54mm_Vertical
J8, J9, J13: Conn_01x04; PinHeader_1x04_P2.54mm_Vertical; Digikey 609-3262-ND
J11, J12: Conn_02x03_Odd_Even; PinHeader_2x03_P2.54mm_Vertical
MK1, MK2, MK3, MK4: Mounting_Hole_PAD; MountingHole_3.2mm_M3_Pad
R16, R17, R18, R19, R21, R22: 10K; R_0603_1608Metric
R20, R23: 330; R_0603_1608Metric
SW1: SW_DIP_x04; SW_DIP_x4_W8.61mm_Slide_LowProfile; Digikey CT2194MST-ND

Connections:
+3V3: J6.5, J7.1, J8.4, J9.4, J11.2, J12.2, J13.3, R16.1, R17.1, R18.1, R19.1, R21.1, R22.1; also elsewhere on the board
GND: D5.1 (K), D6.1 (K), J6.6, J7.3, J8.3, J9.3, J11.6, J12.6, J13.4, MK1.1, MK2.1, MK3.1, MK4.1, SW1.5, SW1.6, SW1.7, SW1.8; also elsewhere on the board
GPIO1: J6.1; also elsewhere on the board
GPIO2: J6.2; also elsewhere on the board
GPIO3: J6.3; also elsewhere on the board
GPIO4: J6.4; also elsewhere on the board
GPIO7: R19.2, SW1.1; also elsewhere on the board
GPIO8: R18.2, SW1.2; also elsewhere on the board
GPIO9: R17.2, SW1.3; also elsewhere on the board
GPIO10: R16.2, SW1.4; also elsewhere on the board
I2C1_SCL: J13.1; also elsewhere on the board
I2C1_SDA: J13.2; also elsewhere on the board
LED1: R20.1; also elsewhere on the board
LED2: R23.1; also elsewhere on the board
NRST: J7.5; also elsewhere on the board
unnamed: D5.2 (A), R20.2
unnamed: D6.2 (A), R23.2
SPI1_MISO: J12.1; also elsewhere on the board
SPI1_MOSI: J12.4; also elsewhere on the board
SPI1_SCK: J12.3; also elsewhere on the board
SPI1_~CS: J12.5, R22.2; also elsewhere on the board
SPI2_MISO: J11.1; also elsewhere on the board
SPI2_MOSI: J11.4; also elsewhere on the board
SPI2_SCK: J11.3; also elsewhere on the board
SPI2_~CS: J11.5, R21.2; also elsewhere on the board
SWCLK: J7.2; also elsewhere on the board
SWDIO: J7.4; also elsewhere on the board
SWO: J7.6; also elsewhere on the board
UART1_RX: J9.1; also elsewhere on the board
UART1_TX: J9.2; also elsewhere on the board
UART2_RX: J8.1; also elsewhere on the board
UART2_TX: J8.2; also elsewhere on the board

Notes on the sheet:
SWD Programming
UART2 (USB)
UART1
I2C1
SPI1
Debug GPIO
For use with ST-Link V2 programmer or discovery board
Debugging LED
SPI2
Pullups on MCU sheet
DIP Switches
Mounting Holes

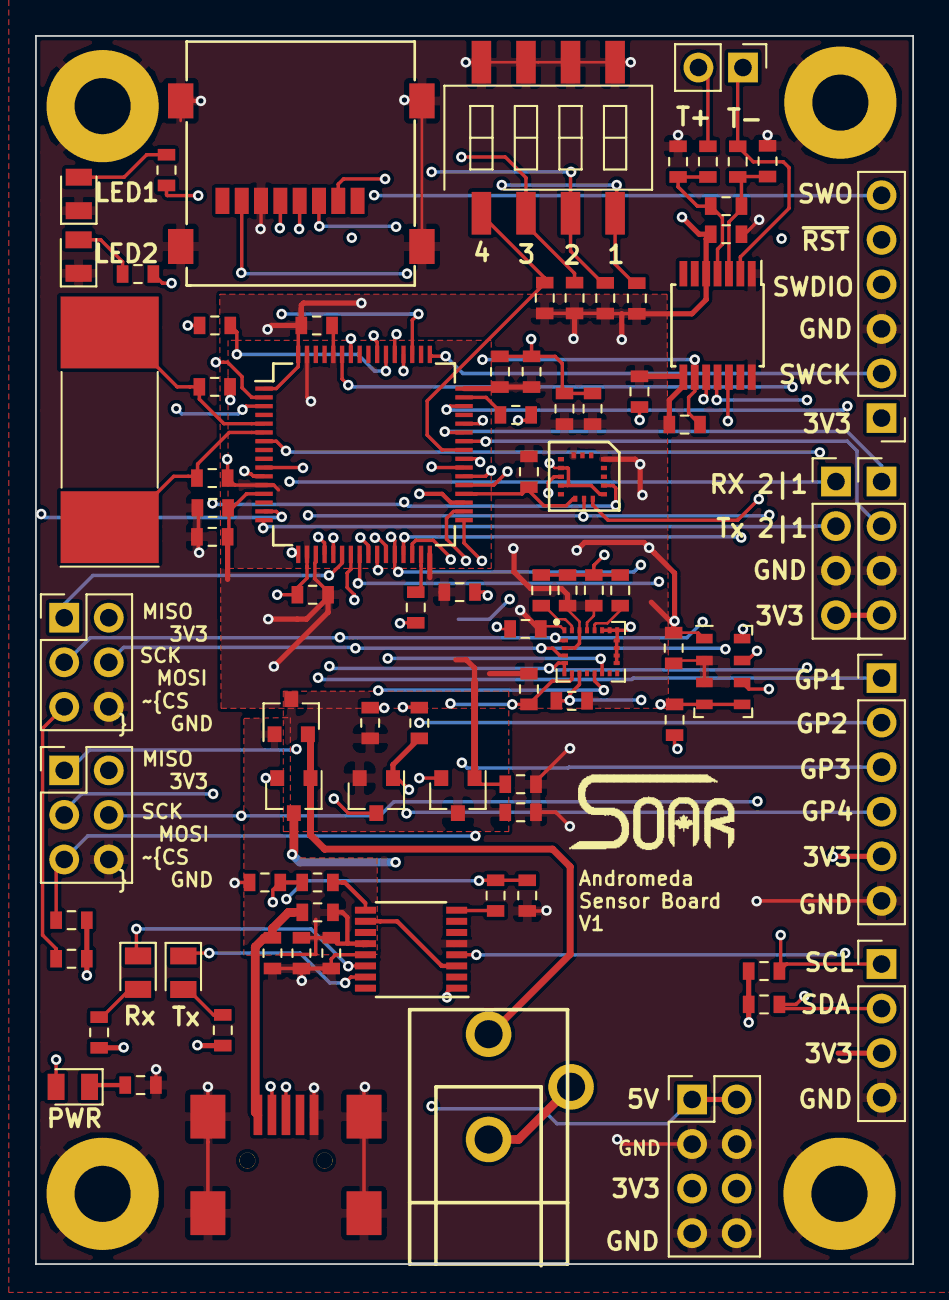
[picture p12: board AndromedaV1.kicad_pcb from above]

Board: 4 copper layers, 50.0 x 70.0 mm, 91 parts (0 on the bottom side), 70 nets.

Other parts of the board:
LOGO_SOAR: LOGO_SOAR

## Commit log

2018-02-18 Initial commit of design files
    [AndromedaV1-B.Cu.gbl, AndromedaV1-B.Mask.gbs, AndromedaV1-F.Cu.gtl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]
2018-02-18 Restructure directories
    [AndromedaV1-B.Cu.gbl, AndromedaV1-B.Mask.gbs, AndromedaV1-F.Cu.gtl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]
